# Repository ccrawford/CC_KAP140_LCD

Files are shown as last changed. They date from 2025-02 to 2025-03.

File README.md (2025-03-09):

> [!NOTE]  
> This repository contains the MobiFlight custom device code and the hardware construction files for my implementation of a KAP140
autopilot using a RP2040 and a 3.12" OLED screen. The MobiFlight profile is for the WBSim C172 which has a more complete implmentation of the KAP140. You can use it with the Asobo KAP140, but will require some mods to the MobiFlight mcc file.

## Prerequisites
** Requires use of a custom MobiFlight board and device (included here) to get the screen to function.
* 3d printer. I use a very old FlashForge Creator Pro 2, so any decent 3d printer will suffice.
* Laser cutter/etcher. I use my local library's Epilog Fusion 60. Alternately, you could cut the PCB with a dremel and paint/hand letter.
* Various hardware and supplies listed [here](/Hardware/Instructions.md)
* More pictures and build instructions in the [Hardware folder](/Hardware)
* See detailed information on the OLED screen [here](/Hardware/NotesOnOLED.md)

## Pictures

<em>Running</em></br>
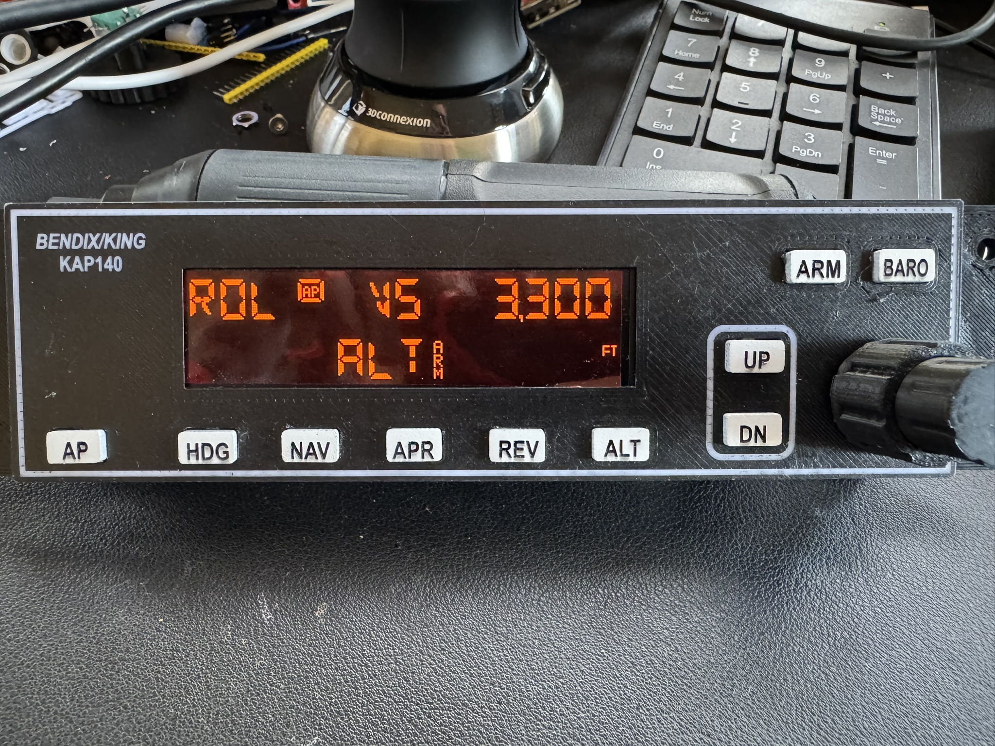
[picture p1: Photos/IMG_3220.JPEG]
Side view


<em>In action YouTube link</em></br>
Video Demo (https://youtu.be/b3xRHRXjemo)

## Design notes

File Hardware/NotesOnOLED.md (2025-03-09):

The OLED display used in this project is a monochrome, 3.12" display with 256x64 resolution.

# Purchasing
You can find these on the usual online stores (Amazon, AliExpress, Ebay). Searching for "OLED 3.12" will usually pull up a lot of examples. They are about $15-18 on Ali, $20-30 on the other places. If you find one suspiciously inexpensive, (under $10) double check to see that it includes the interface board. 

**Do NOT buy one that shows a hanging ribbon connector.**</br>
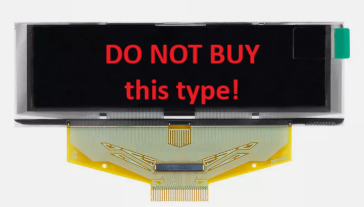
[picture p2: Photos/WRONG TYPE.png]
NOT THIS ONE


</br>
**Do buy one with the 16 pin header and the configurable interface**

[This one](https://www.aliexpress.us/item/3256805799056965.html)

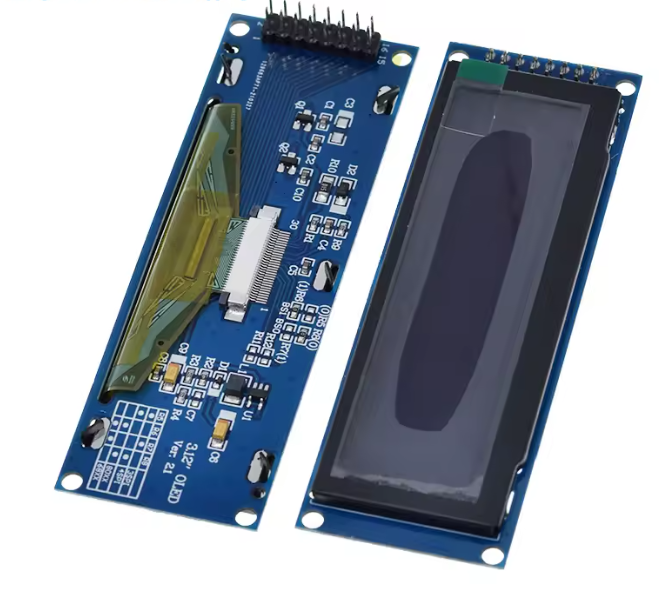
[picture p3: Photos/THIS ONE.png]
This one


### Color
They come in four, monochrome colors. The color is up to you, but I use white and the put some red-orange transparency film on it to make it "LED Orange".  Oracal 8300 film, color 033 works well. Google "Oracal 8300 033". It's about $2/sheet, but shipping costs will suggest buying a few other colors at the same time. Get some reds and greys. I like the light greys on top of 7-segment displays to make them look cleaner. 

# Configuring the display interface
One important note: These devices support different interfaces by moving jumpers which are 0 ohm, SMD resistors on the board. They typically come with the resistors in the 80xx configuration. On the board in the image, look at the silkscreened table on the device. What we want to use is the 4-wire SPI interface (4SPI).

We need to have resistors R5 and R8. However right now we have R6 and R8. So, take your soldering iron and remove R6 and move it to R5. I recommend using a soldering iron, not a hot air rework station. If you lose the 0 Ohm resistor when you desolder it from R6, you can bridge R5 with a nice blob of solder. Either will work. Inspect your work and make sure R8 is still in place. A continuity meter is helpful here. **If you don't have this set properly, your screen will not work!**

</br><em>Interface configuration table circled in red, jumper location in yellow. If you look closely, you can see this one configured for 80xx. We want 4SPI</em></br>
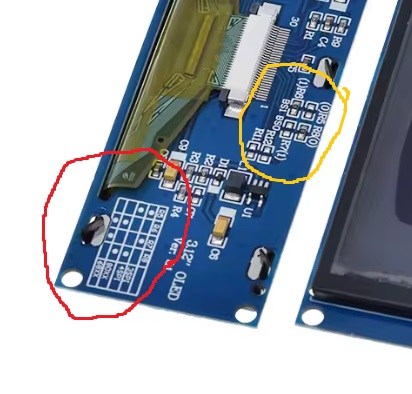
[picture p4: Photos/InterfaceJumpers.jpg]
Interface Jumpers


# Conencting the display to the RP2040

## TL;DR: 

| RP2040 | OLED | Comment |
|---|---|---|
| 18 | D0: Pin4 | SCK/Clock |
| 19 | D1: Pin5 | Data (MOSI) |
| 17 (arbitrary) | 16 | CS |
| 20 (arbitrary) | 14 | DC |
| 21 (arbitrary) | 15 | Reset |
| GND | 1 | Ground |
| VBUS | 2 | 5v |

### Side note on channels
The four wires in 4-wire SPI (Serial Peripheral Interface) are:

MOSI (Master Out Slave In) - Data sent from the master device to the slave device
MISO (Master In Slave Out) - Data sent from the slave device to the master device (Not used here)
SCLK (Serial Clock) - The clock signal generated by the master to synchronize data transmission
SS/CS (Slave Select/Chip Select) - Signal used by the master to select which slave device to communicate with

These four lines create a full-duplex communication channel, allowing simultaneous bidirectional data transfer between devices. The master device controls the clock and selects which slave to communicate with, while data flows in both directions on separate lines. However for our interface, there is no display-out communication.

DC and RESET are not part of the standard 4-wire SPI interface - they're additional control lines often used with specific peripheral devices, particularly displays:

DC (Data/Command) - This line indicates whether the data being sent on the MOSI line should be interpreted as a command (DC=0) or as display data (DC=1). It's commonly used with display controllers like those in LCD or OLED screens to differentiate between commands (like "set cursor position") and actual pixel data.
RESET - This is a hardware reset line used to initialize or restart the peripheral device. Pulling this line low (active-low) forces the device to return to its initial state. This is useful during power-up sequences or when recovering from error conditions.

## The RP2040 interface

Now that we have it configured for 4-wire SPI let's get it wired to the RP2040. We are using SPI0 on the RP2040. While the library supports software SPI with user selectable pins, the screen refresh rate is much too slow. 

The default hardware SPI pins for SPI0 are:
    - SCK (Clock): GPIO 18
    - MOSI (Data Out): GPIO 19
    - MISO (Data In, not used here)
    - Chip Select (CS) Any GPIO you assign (we will use 17)
  These two aren't part of 4-wire SPI, but are needed by the display.
    - Data/Command (DC):  (We will use 14)
    - Reset: Any GPIO you assign. (We will use 21)

## The OLED interface

On the OLED the resistors mentioned above specify how the pins are to be used. Study the pin numbering on the header. They start with 1 on the bottom right and go up to 16 on the upper left. It's easy to get them mixed up!

Here is the info from the manufacturer:

| Pin No. | Symbol |
|---|---|
| 1 | VSS/GND |
| 2 | VCC-IN |
| 3 | NC |
| 4 | D0/CLK |
| 5 | D1/DIN |
| 6 | D2 |
| 7 | D3 |
| 8 | D4 |
| 9 | D5 |
| 10 | D6 |
| 11 | D7 |
| 12 | E/RD#  |
| 13 | R/W# |
| 14 | D/C# |
| 15 | RES# |
| 16 | CS# |

And same info with more detail.

| Pin No. | Symbol | I/O | Function |
|---|---|-----|---|
| 1 | Vss | P | Ground of Logic Circuit<br>This is a ground pin. It also acts as a reference for the logic pins. It must be connected to external ground. |
| 2 | VBAT | 3...5V | Power Supply for Display Module Circuit<br>This is a voltage supply pin. It connected to external source. |
| 3 | NC | - | Please let it Float. |
| 4--11 | DB0—DB7 | I/O | Host Data Input/Output Bus<br>These pins are 8-bit bi-directional data bus to be connected to the microprocessor's data bus. When serial mode is selected, D1 will be the serial data input SDIN and D0 will be the serial clock input SCLK. |
| 12 | /RD | I | Read/Write Enable or Read<br>This pin is MCU interface input. When interfacing to an 68XX-series microprocessor, this pin will be used as the Enable(E) signal. Read/Write operation is initiated when this pin is pulled high and the CS is pulled low. When connecting to an 80XX-microprocessor,this pin receives the Read(RD) signal. Data read operation is initiated when this pin is pulled low CS is pulled low. |
| 13 | /WR | I | Read/Write Select or Write<br>This pin is MCU interface input. When interfacing to an 68XX-series microprocessor, this pin will be used as Read/Write (R/W) selection input. Pull this pin to "High" for read mode and pull it to "Low" for write mode. When 80XX interface mode is selected, this pin will be the Write (WR) input. Data write operation is initiated when this pin is pulled low and the CS is pulled low. |
| 14 | /DC | I | Data/Command Control<br>This pin is Data/Command control pin. When the pin is pulled high, the input at D7~D0 is treated as display data. When the pin is pulled low, the input at D7~D0 will be transferred to the command register. For detail relationship to MCU interface signals, please refer to the Timing Characteristics Diagrams. |
| 15 | /Reset | I | Power Reset for Controller and Driver<br>This pin is reset signal input. When the pin is low, initialization of the chip is executed. |
| 16 | /CS | I | Chip Select<br>This pin is the chip select input. The chip is enabled for MCU communication only when CS# is pulled low. |

## Note on power
It's probably not best practice to run the display off of the microcontroller power supply. I use "VBUS", which is connected to the USB power supply. I've measured current draw of the completed rp2040/oled device at 200mA when on and 30mA with display off. This is well within the 500mA baseline for a USB connection, but if you have an unpowered hub with multiple devices trying to pull 200 each, it's possible that the hub will be insufficient to power everything.

If you are running this setup off of an unpowered or underpowered hub (which is fairly common for sim-pits) and the display doesn't light or rp2040 doesn't show up, try connecting to a powered hub or on a hub where this is the only device plugged in. I always recommend running home-built USB devices on a hub, not on your PC/laptop's ports as a little protection against shorts or back-fed power. Not pefect, but a little insurance.

## Physical connections
I use 26 awg silicone multi-strand wire. About 10cm long. I then upload a quick test program to the RP2040 to make sure everything is working before wiring and building any more. You will need to remove the pin headers as well. You can use dupont wires (and that might be a good idea when you're testing things) but they will 100% work themselves free and cause problems if you try to use them in the final product. Unsolder the headers, clean up the old solder, then tin the wires and solder directly to the board. Note that the wires should enter from the component side of the display (so your soldering iron is working on the side where you cannot see the pin numbers. I've messed that up a couple times!)
</br><em>I need a better picture, but here you can see the wires going into the back of the display</em>
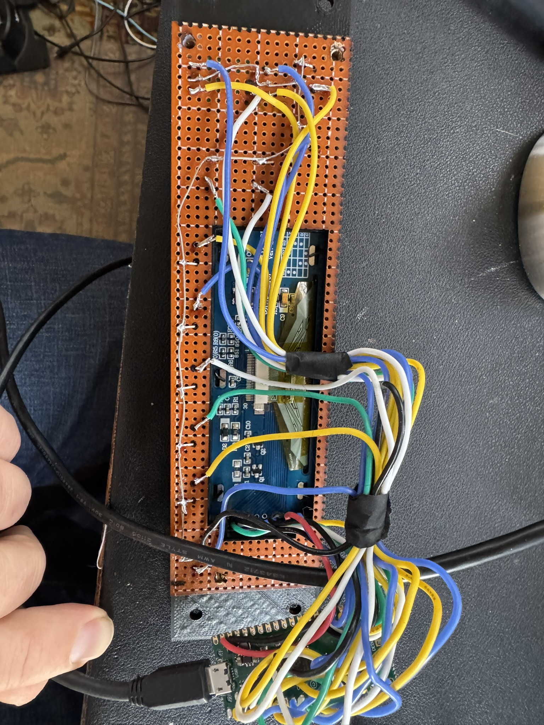
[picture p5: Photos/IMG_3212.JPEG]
Wiring
</br>

# Summary
Ok, so end of the day, here's how we will run the wires:

| RP2040 | OLED | Comment |
|---|---|---|
| 18 | D0: Pin4 | SCK/Clock |
| 19 | D1: Pin5 | Data (MOSI/MISO) |
| 17 (arbitrary) | 16 | CS |
| 20 (arbitrary) | 14 | DC |
| 21 (arbitrary) | 15 | Reset |
| GND | 1 | Ground |
| VBUS | 2 | 5v |

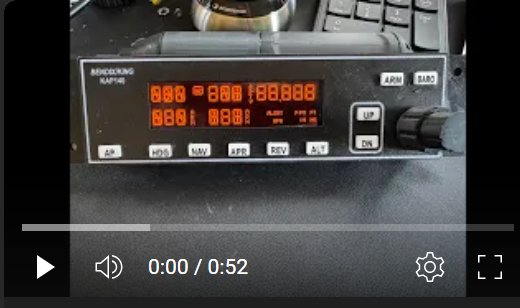
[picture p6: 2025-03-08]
Photos/videoThumbnail.png

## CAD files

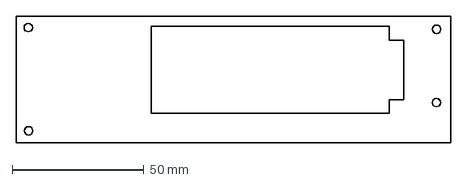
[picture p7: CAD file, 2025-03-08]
Hardware/KAP140_Protoboard_LaserCut.dxf
165.1 x 48.3 mm

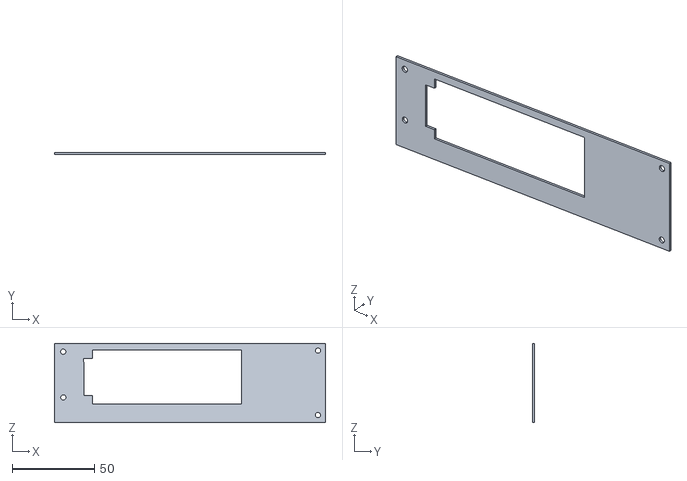
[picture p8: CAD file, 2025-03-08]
Hardware/KAP140_PCB_DO_NOT_PRINT.stl
165.1 x 1.20 x 48.3

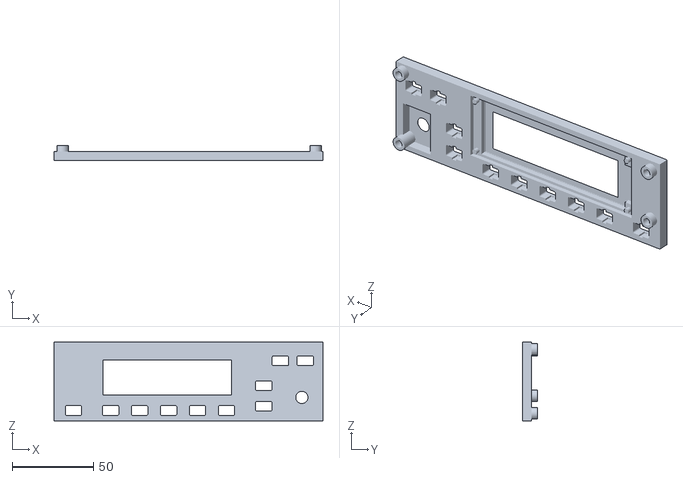
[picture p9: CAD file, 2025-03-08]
Hardware/KAP140_Fascia.stl
165.1 x 9.50 x 48.3

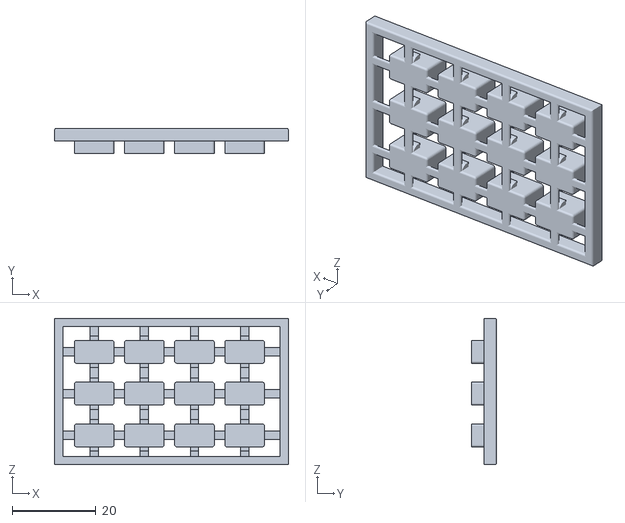
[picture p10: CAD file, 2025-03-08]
Hardware/KAP140_Button_Matrix.stl
56.0 x 6.00 x 35.0

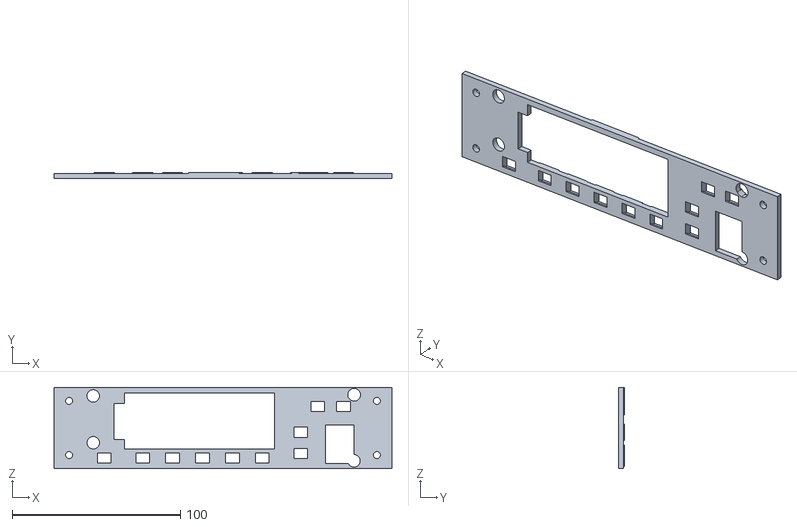
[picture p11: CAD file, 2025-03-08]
Hardware/KAP140_BackingPlate.stl
201.1 x 3.80 x 48.3

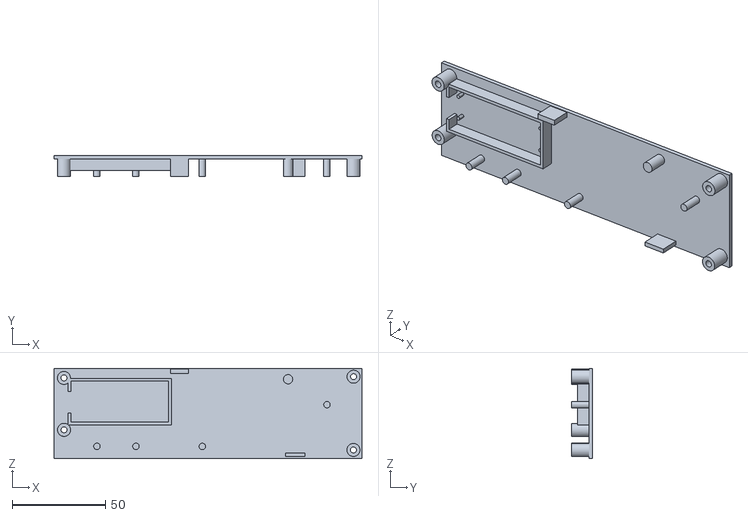
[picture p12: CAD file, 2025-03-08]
Hardware/KAP140_BasePlate.stl
165.1 x 11.3 x 48.3

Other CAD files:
Hardware/KAP140 Buttons v3.f3d
Hardware/KAP140_LCD v14.f3z

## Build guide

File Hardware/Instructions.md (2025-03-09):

## Files
The *.f3d files are Fusion archives if you want to mod.
The STLs are as I printed them. 
The SVGs are for the laser. 
    In the PCB dxf file, red is used in vector mode on the laser cutter to cut the protoboard to size.
    In the ButtonLettering dxf file, red is used to etch the letters on the button matrix STL. 
    Similarly, in the Fascia Lettering, the red is used to etch the Fascia STL.

Note about materials: I'll try to give a search term and a link to an AliExpress source.

## Bill of Materials:

I'd say the total cost here is around $30. The screen at $15, the dual encoder at $5, the switches at about $3, protoboard at $2, and the rp2040 at $3, plus misc filament, hardware, wire. (AliExpress shipped prices. Higher for domestic sources.)

1. PLA in white and black.
2. Protoboard at least 170x50mm. I use the brown phenolic protoboard with single-side solderable copper. https://www.aliexpress.us/item/3256806823414882.html Search "prototype board pcb" and look for the brown ones.
3. 10 switches. This design uses "8x8 silent silicone switches" but not sure that I really like those as there's no tactile feedback. Only a mushy press. https://www.aliexpress.us/item/3256804402559566.html Search "8x8 silicone switch"
4. 1 Dual rotary encoder. Search EC11EBB24C03. You can use the green or the yellow ones. Green are more common. Yellow are cheaper.
5. 1 RP2040 microprocessor and USB cable. I use the most common $2-3 type. Aka Raspberry Pi Pico. No wireless necessary. You want one WITHOUT headers.
6. 1 3.12" OLED display. You can use whatever color you want. I like to get the white ones and then cover with ORACAL film to get the proper color display. Search: 3.12 OLED. You must get one with the 4-wire SPI interface. Do NOT just get a bare screen or one with just a dangling ribbon cable. https://www.aliexpress.us/item/3256805975276793.html
6b. Optional: If you want the orange color, get some Oracal 8300, color 033 "red orange" to cover the display. 
7. Hook up wire. Personal preference here, but I like to use 30 AWG wire-wrap wire like this: https://www.aliexpress.us/item/3256802844140015.html but I use 26 awg silicone wire for the display. https://www.aliexpress.us/item/3256807070653563.html
8. 4 m3 x 20 bolts. Head type doesn't really matter. Button head probably the best choice. https://www.aliexpress.us/item/3256806241082021.html search: m3 20 and pick.
9. 4 m3 inserts: I like these as I typically assemble/disassmble a lot during construction. You could skip these, but may need to make the bosses where the screws anchor a bit tighter. https://www.aliexpress.us/item/3256803396040989.html search: m3 brass insert

## Instructions: 
1. 3d print white: Fascia. 3d print black, buttons, backing plate, base plate, knobs. 
2. Spray paint the fascia black and the buttons white. I use 3-5 light coats, 10-15 mintues apart.
3. Laser cut the protoboard. Alignment of the holes in the protoboard with the template is critical here. Cut it so the copper side is face down!
4. Laser etch the buttons and fascia, using care to center lettering.
5. Use the backing plate as a template to place the switches and encoder on the cut protoboard. Double check the alignment. Get the switches all the way down on the board with the connected terminals on the switches aligned horizontally.
6. Start soldering! 
7.  Start with the display. **See detailed information on the display configuration [here](NotesOnOLED.md) **
    Configure the display for 4SPI, and remove the headers.

    Using Hardware SPI:
    | RP2040 pin | OLED pin | Comment |
    | --- | --- | --- |
    | 18 | D0: Pin4 | SCK/Clock |
    | 19 | D1: Pin5 | Data (MOSI/MISO) |
    | 17 | 16 | CS |
    | 20 | 14 | DC |
    | 21 | 15 | Reset |
    | GND | 1 | Ground |
    | VBUS | 2 | 5v |

8. Solder the switches
    I use a bare piece of single-strand wire to run a ground line across all the switches, then run awg30 to each switch/encoder pin to the RP2040
    You must use the correct pins for the display, however you can use whatever pins you want to connect the switches, but if you want to use my Mobiflight config, you'll need to follow this config:

```
<CustomDevice Name="KAP140_LCD" CustomType="CC_KAP140_LCD" Pins="18|19|17|20|21" Config="">
    <ConfiguredPins>
      <string>18</string>
      <string>19</string>
      <string>17</string>
      <string>20</string>
      <string>21</string>
    </ConfiguredPins>
</CustomDevice>
<Button Name="ALT_ENC_BUTTON" Pin="2" />
<Encoder Name="ALT_ENC_OUTER" PinLeft="4" PinRight="3" EncoderType="2" />
<Encoder Name="ALT_ENC_INNER" PinLeft="1" PinRight="15" EncoderType="2" />
<Button Name="BARO_BUTTON" Pin="5" />
<Button Name="ARM_BUTTON" Pin="6" />
<Button Name="UP_BUTTON" Pin="7" />
<Button Name="DN_BUTTON" Pin="8" />
<Button Name="ALT_BUTTON" Pin="9" />
<Button Name="REV_BUTTON" Pin="10" />
<Button Name="APR_BUTTON" Pin="11" />
<Button Name="NAV_BUTTON" Pin="12" />
<Button Name="HDG_BUTTON" Pin="13" />
<Button Name="AP_BUTTON" Pin="14" />
```

8. Assemble. Should be self explanatory. Note that the rp2040 "floats". I use a little sticky stuff to hold it in place. I also use some kapton tape to make sure the screen is insulated, and I tape up the connector wires into bundles.

9. Flash the rp2040 (I usually do this much earlier in the project!) 
    Copy contents of the Community folder (under CC_KAP140_LCD) to your mobiflight community directory.
    Plug in the rp2040 and start mobiflight
    Configure the module using the mfmc in the "Mobiflight Runtime Config" directory (if you didn't follow my pin numbering above for the buttons, adjust there)
    Open the KAP140LCD.mcc file in Mobiflight and give it a test. 
    NOTE the mcc file is written for the WBSim C172! If you are using the base C172 from Asobo you will need to adjust, and some features will not be available.

## Photos
<em>Side View:</em></br>
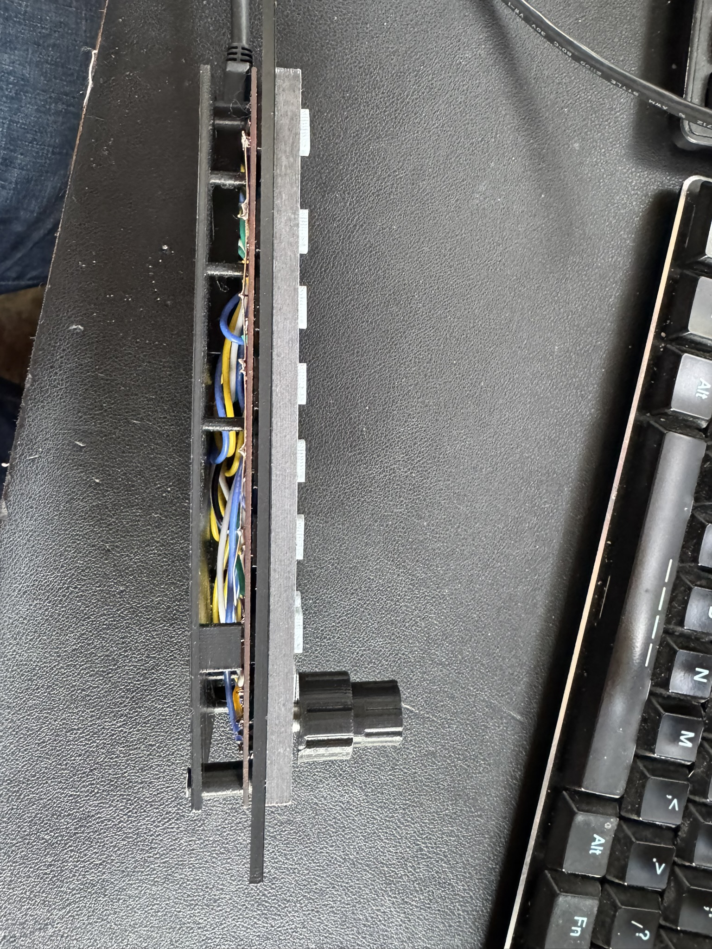
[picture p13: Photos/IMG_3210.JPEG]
Side view


<em>Back cover removed:</em></br>
Back removed

<em>Perfboard opposite side and backing plate:</em></br>
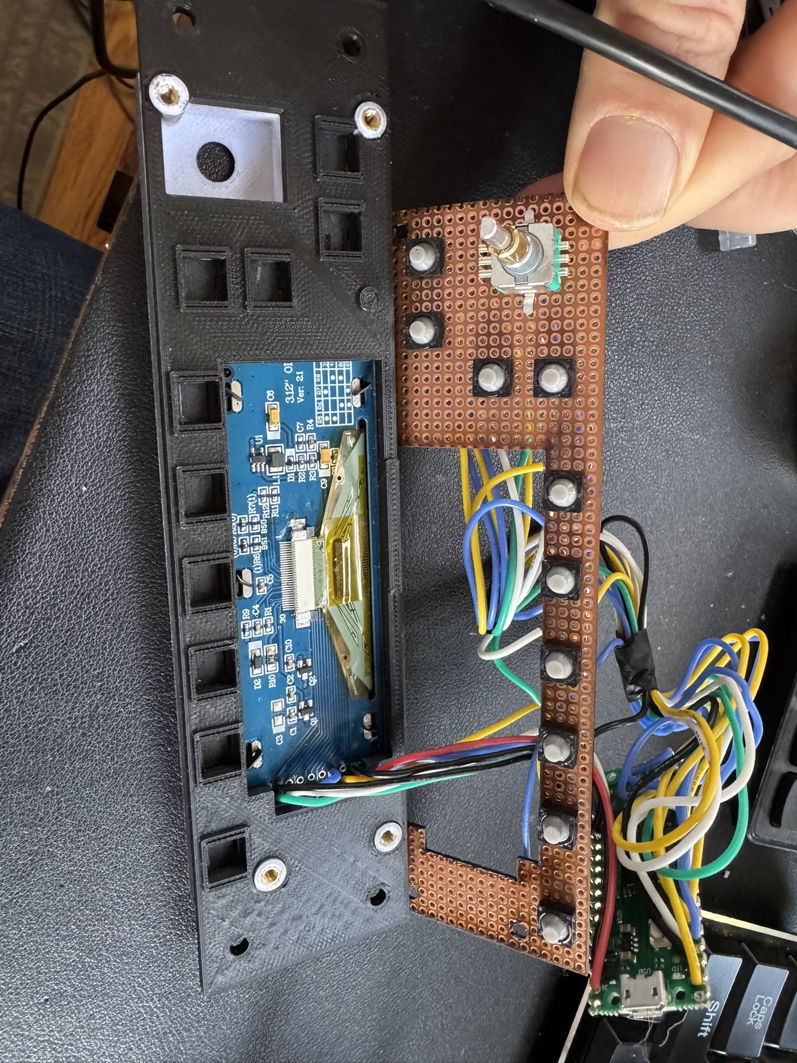
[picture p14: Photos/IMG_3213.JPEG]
Pcb removed


<em>Get a display that looks like this:</em></br>
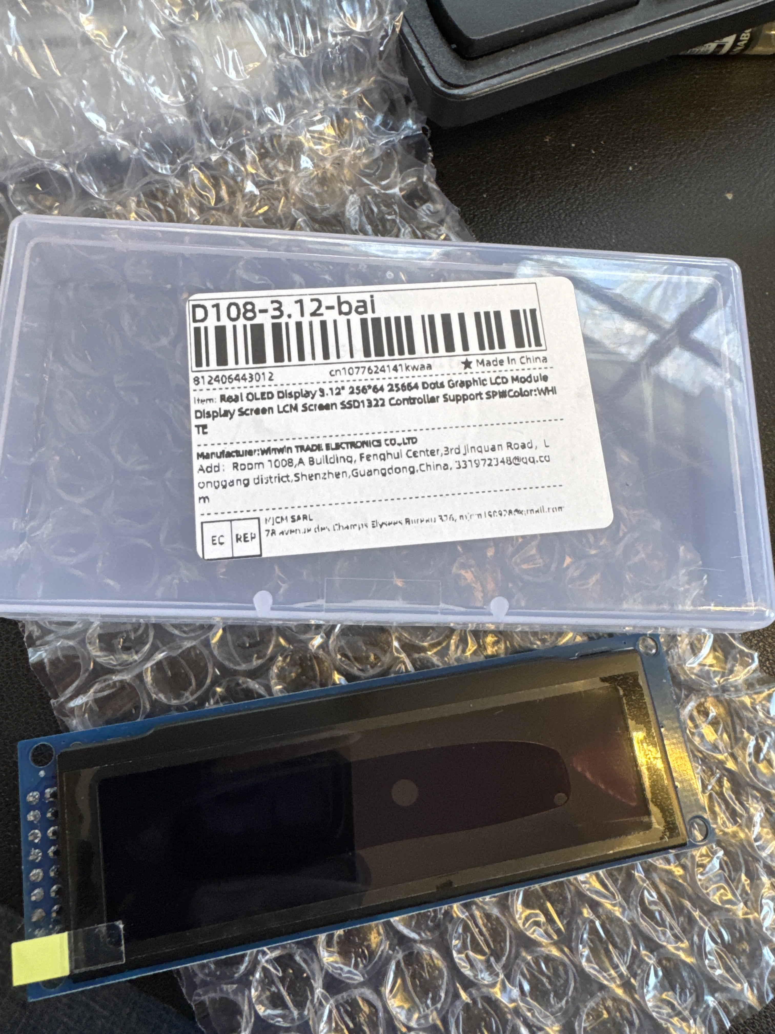
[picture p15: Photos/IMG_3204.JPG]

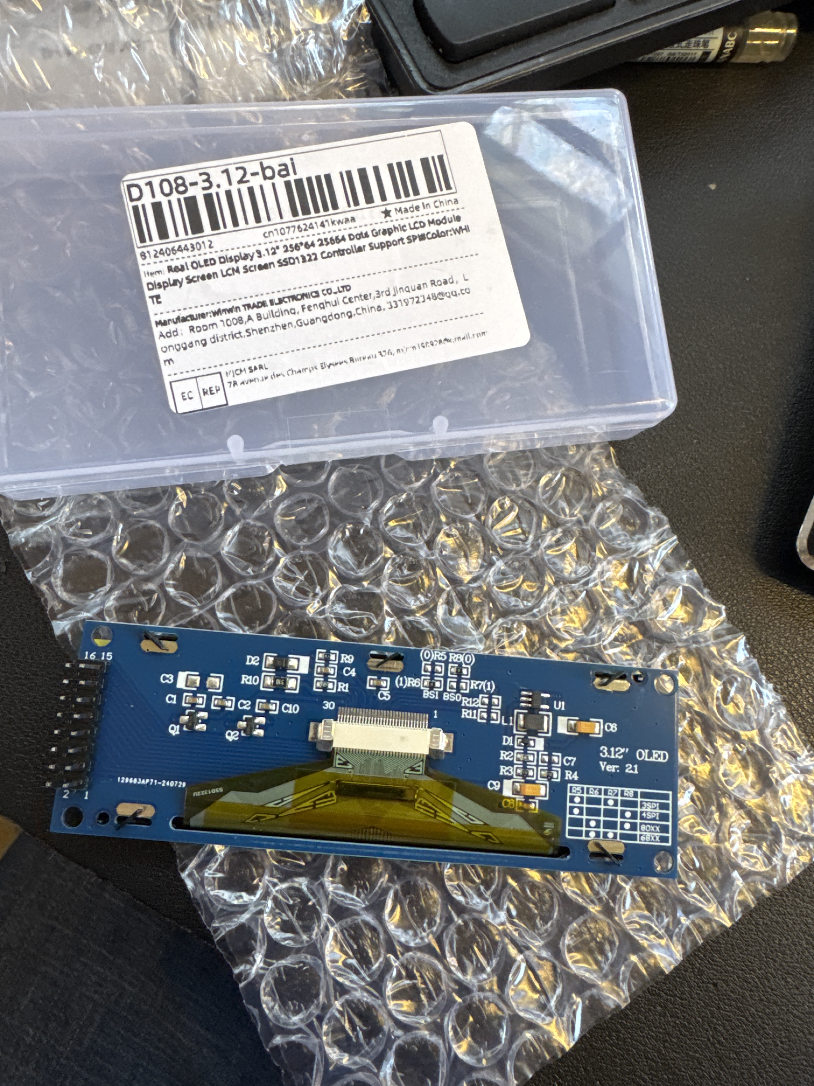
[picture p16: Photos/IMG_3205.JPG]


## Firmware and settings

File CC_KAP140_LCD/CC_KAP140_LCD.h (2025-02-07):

#pragma once

#include "Arduino.h"
#include <U8g2lib.h>
#include "kap140_20b_font_constants.h"
#include "kap140_20b_font.h"

// Horizontal positions
#define K140_LEFT_EDGE_X 1
#define AP_X (K140_LEFT_EDGE_X + 64)
#define MID_TEXT_X (AP_X + 22)
#define PT_X (MID_TEXT_X + 62)
#define RIGHT_TEXT_X (PT_X + 11)
#define FPM_X (RIGHT_TEXT_X + 60)
#define FT_X (FPM_X + 23)
#define ALERT_X (RIGHT_TEXT_X + 17)

// Vertical positions
#define TOP_LINE_Y 27
#define BOT_LINE_Y 62

class CC_KAP140_LCD
{
public:
    CC_KAP140_LCD(uint8_t cs, uint8_t dc, uint8_t reset );
    void begin();
    void attach();
    void detach();
    void set(int16_t messageID, char *setPoint);
    void update();

private:
    bool _initialised;
    bool _apHasPower = false;
    bool _apWasActive = false;
    bool _apActive = false;
    bool _selfTestMode = false;
    bool _trimUp = false;
    bool _trimDown = false;
    bool _isRevArm = false;
    bool _isNavArm = false;
    bool _isAprArm = false;
    bool _alertIndicator = false;
    int _rightBlockMode = 0;     // 1: VS, 2: ALT, 3: GS, 4: Baro Mb, 5: Baro In HG
    int _rightBlockData = 0;     // Just a number to display in in the right side info: Altitude, FPM, Baro.
    int _altAlerter = 0;         // Alt alerter altitude
    int _baroMode = 0;           // Are we displaying barometric pressure 0: no, 1: HPA, 2: In Hg
    bool _baro_blinking = false; // used to clear display after baro warning after PFT.
    bool _startPFT = false;      // trigger the pft.
    int _lateralMode = 0;        // 0: none, 1: ROL, 2: HDG, 3: NAV, 4: APR
    int _lateralArmMode = 0;     // 0: none, 1: NAV, 2: APR, 3:REV, 4: GS
    int _verticalArmMode = 0;    // 0: none, 1: ALT
    bool _tempVsMode = false;
    bool _apOffAlertMode = false;
    long unsigned int _apOffAlertTimer = 0;

    U8G2_SSD1322_NHD_256X64_F_4W_HW_SPI u8g2;

    void drawDisplay();
    void fillTestPattern();
    void fillRightData();
    void fillUnits();
    void fillSelfTest();
    char *formatComma(int number);

};

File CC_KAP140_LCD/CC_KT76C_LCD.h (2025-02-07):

#pragma once

#include "Arduino.h"
#include <U8g2lib.h>
#include "kap140_20b_font_constants.h"
#include "kap140_20b_font.h"

// Horizontal positions
#define KT76_FL_X 20
#define KT76_FL_IND_X KT76_FL_X + 2
#define KT76_SQUAWK_X KT76_FL_X + 150
#define KT76_ALT_X (KT76_SQUAWK_X - 68)
#define KT76_ON_X  (KT76_SQUAWK_X - 40)
#define KT76_R_X  (KT76_SQUAWK_X - 10)

// Vertical positions
#define KT76_MAIN_Y 40
#define KT76_INDICATOR_UPPER_Y (KT76_MAIN_Y - 14)
#define KT76_INDICATOR_LOWER_Y (KT76_MAIN_Y + 7)

#define NEW_CODE_TIMEOUT_MS 3000

// 0 = Off, 1 = Standby,2 = Test, 3 = On, 4 = Alt, 5 = Ground
enum xpdrMode
{
  Off = 0,
  Standby,
  Test,
  On,
  Alt,
  Ground
};


class CC_KT76C_LCD
{
public:
  CC_KT76C_LCD(uint8_t cs, uint8_t dc, uint8_t reset);
  void begin();
  void attach();
  void detach();
  void set(int16_t messageID, char *setPoint);
  void update();

private:
  bool _initialised;
  bool _hasPower = false;

  bool _altTransmitting = false; // Turn on/off the R
  bool _selfTestMode = false;
  xpdrMode _curMode = xpdrMode::Off;
  int _curCompleteCode = 0;
  int _pressureAltFL = 0;
  int _lastNumberPressed = 0;
  bool _clearPressed = false;
  bool _vfrPressed = false;
  bool _vfrAssignPressed = false;
  int _curVFRCode = 1200;
  unsigned long _numChangeTimer = 0;
  bool _altIsTransmitting = false;
  bool _keyPressProcessed = true;
  bool _newCodeInProcess = false;
  int _newCodePlace = 1000;  // What we will multiply the next number by
  int _newCode = 0;  // When user updates code, hold temp value here.
  
  int _curPos = 0; // used with debugging

  U8G2_SSD1322_NHD_256X64_F_4W_HW_SPI u8g2;

  //  U8G2_SSD1322_NHD_256X64_F_4W_SW_SPI u8g2;

  void drawDisplay();
  void fillTestPattern();
  void fillCode();
  void fillFL();
  void fillOn();
  void fillSby();
  void processClear();
  void showAltTransmit();
  void processKeyPress();
  void resetCodeUpdate();
};

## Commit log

2025-01-21 Working with hardware SPI
2025-01-21 Added font defintion file. Added mobiflight connector file.
2025-01-31 Working. About to go after Pin definitions
2025-02-01 Fixed right-hand layout and spacing. Minor refactoring. Included fonts in repo.
    [CC_KAP140_LCD.h]
2025-02-07 KT76C Device working
2025-03-08 Added construction files and instructions.
    [KAP140 Buttons v3.f3d, KAP140_BackingPlate.stl, KAP140_BasePlate.stl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]
